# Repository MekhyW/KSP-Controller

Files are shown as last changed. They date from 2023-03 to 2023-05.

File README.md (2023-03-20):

# Projeto Embarcados

Desenvolvendo um controle remoto Bluetooth.

### Integrantes

- Ariel Leventhal
- Rafael Katri
- Felipe Catapano

### Ideia

A ideia do projeto é criar um controle bluetooth que simula um mission controller realista para o jogo Kerbal Space Program, assim aumentando a imersão do jogo e providenciando feedback visual diretamente no controle.
Com isso, os jogadores podem ter uma experiência mais envolvente e realista, sentindo-se como se estivessem realmente no comando de uma missão espacial. 
Para isso será usado uma placa SAME70-XPLD com vários periféricos e um módulo bluetooth HC-05.

### O Que é o Kerbal Space Program?

KSP
Kerbal Space Program é um jogo de simulação espacial desenvolvido pela Squad e lançado em 2011. Nele, o jogador assume o papel de administrador de uma agência espacial fictícia e deve construir e gerenciar naves espaciais, realizar missões de exploração e pesquisa em um sistema solar simulado.

O jogo possui um alto grau de realismo, com física e mecânica orbital precisas, o que significa que o jogador deve levar em conta fatores como a gravidade, a atmosfera, o peso e o empuxo ao projetar e lançar suas naves. Além disso, os kerbals, criaturas humanoides verdes que habitam o jogo, são os tripulantes dessas naves e também possuem suas próprias habilidades e limitações.

Kerbal Space Program é um jogo desafiador e educativo, que exige planejamento cuidadoso e pensamento crítico para alcançar objetivos no espaço. Ele também se tornou um fenômeno na comunidade de jogos e exploração espacial, com muitos jogadores construindo e compartilhando suas próprias criações e mods para o jogo.

### Nome
Valdisnei da Chroma 2:
16.6 milhões de cores

### Usuários 

Jogadores de Kerbal Space Program e admiradores do valdisnei.

### Software/Jogo 

Kerbal space  program (KSP), utilizando mod kRPC
O mod possibilita que o jogo seja controlado através da seguinte biblioteca: https://krpc.github.io/krpc/

### Jornada do usuários
Jornada 1:

&nbsp;&nbsp;&nbsp;&nbsp;&nbsp;&nbsp;O usuário entra no jogo Kerbal Space e ativa o mod de comunicação com o controle.  Em seguida, ele inicia a gameplay usando o slider de throttle (potenciometro linear) e aperta botão de estagio para acionar os motores da nave. Antes de entrar em órbita, o usuário vê pela resposta visual dos botões de Action Group que o combustível está acabando. 
        Ele usa a chave alavanca de Abort para iniciar o protocolo de emergência que ejeta a capsula do piloto e arma o paraquedas para ser aberto automaticamente quando a velocidade e altitude forem adequadas.

Jornada 2:

&nbsp;&nbsp;&nbsp;&nbsp;&nbsp;&nbsp;O usuário entra no jogo Kerbal Space e ativa o mod de comunicação com o controle. Em seguida, ele inicia a gameplay usando o slider de throttle (potenciometro linear) e aperta botão de estagio para acionar os motores da nave. Através das leds o jogador ve que o combustivel do primeiro estagio acabou entao ele aperta botao stage para fazer separacao de estagio. Em seguida o combustivel do segundo estagio acaba tambem (essa e uma missao sub-orbital). Entao o jogador aperta o botao estagio novamente para ejetar o motor, e ativa o action group de paraquedas.

### Comandos/ Feedbacks do jogo

#### Comandos
* Throttle 
* Abort
* Actions groups (paraquedas, trem de pouso, freio, etc); por volta de 7.
* Proximo estagio
* Controle de estabilidade automatico
* Controle de reacao

#### Feeback

* Estado dos Actions groups (paraquedas, trem de pouso, freio, etc); por volta de 7
* Estado da missao
* Estado Controle de estabilidade automatico
* Estado Controle de reacao
* Niveis de combustivel e Agente Oxidante

## In/OUT
#### IN
* Throttle: Potenciometro Linear
* Abort: Chave alanvaca
* Actions groups (paraquedas, trem de pouso, freio, etc); por volta de 7: Push button Retroiluminado.
* Proximo estagio: Push button retro iluminado
* Controle de estabilidade automatico: Chave alavanca para ativar e  Push button RGB para ciclar modos
* Controle de reacao: push button retroiluminado

#### Out

* Estado dos Actions groups (paraquedas, trem de pouso, freio, etc); por volta de 7: Led dos botoes
* Estado da missao: led do botao de estagio
* Estado Controle de estabilidade automatico: Cor da led do botao
* Estado Controle de reacao: Led do botao
* Niveis de combustivel e Agente Oxidante: Segmento de fita led RGB.
### Design

O design do controle foi inspirado nas seguintes criações da comunidade de KSP:
KSP
KSP
KSP

O nosso design segue esse layout:
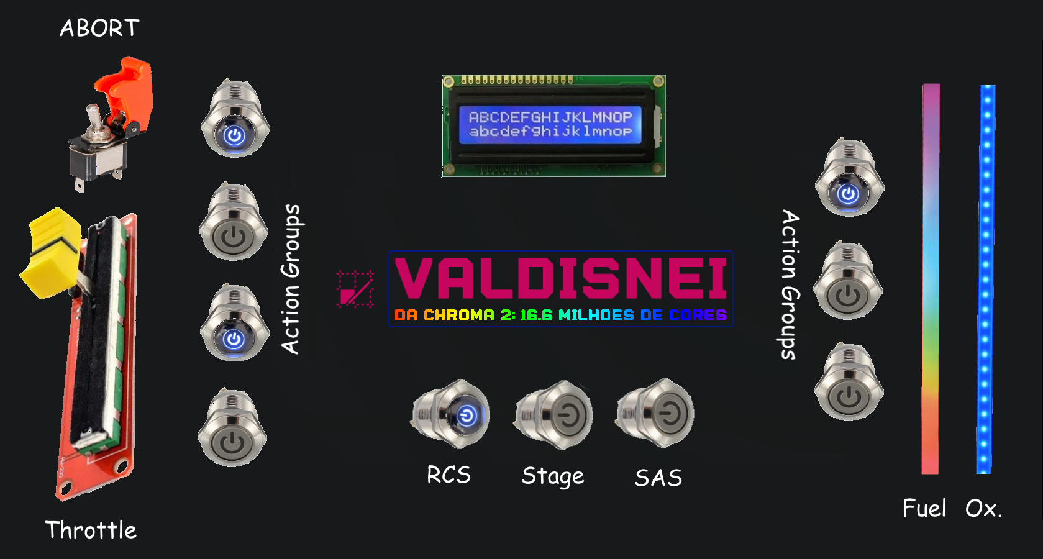
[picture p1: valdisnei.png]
KSP


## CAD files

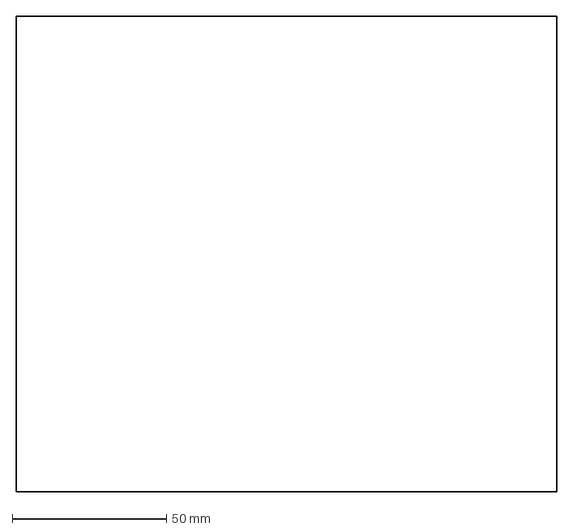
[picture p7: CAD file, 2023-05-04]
Case 3D/box_floor.dxf
175.2 x 154.0 mm

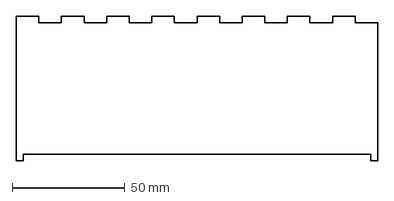
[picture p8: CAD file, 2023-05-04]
Case 3D/box_side.dxf
160.0 x 64.0 mm

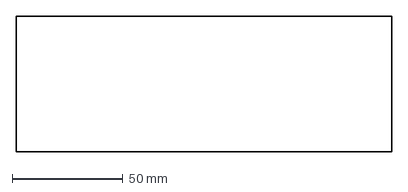
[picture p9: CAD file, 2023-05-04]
Case 3D/box_back.dxf
169.2 x 61.0 mm

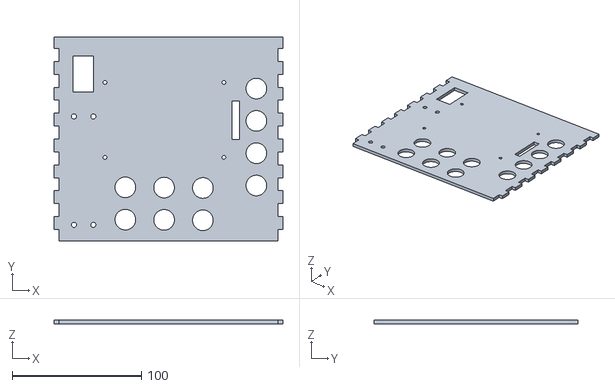
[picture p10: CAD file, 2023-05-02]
Case 3D/tampa.stl
177.2 x 158.0 x 3.00

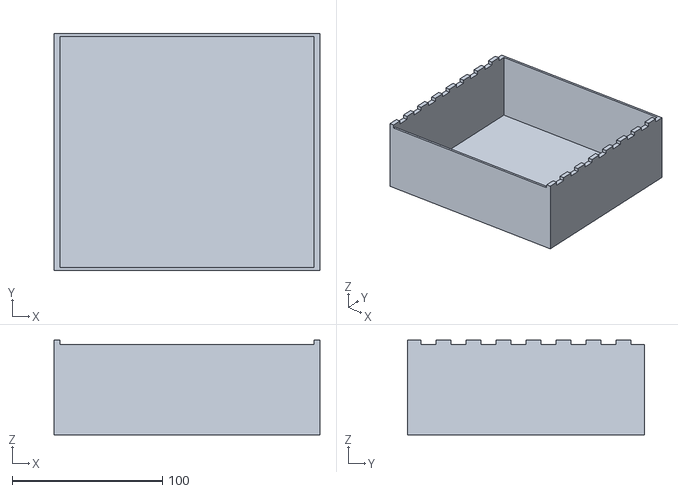
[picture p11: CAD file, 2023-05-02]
Case 3D/caixa.stl
177.2 x 158.0 x 63.0

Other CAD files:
Case 3D/controller.f3d

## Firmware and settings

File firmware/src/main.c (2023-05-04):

#include "abort.h"
#include "backlit-buttons.h"
#include "conf_board.h"
#include "throttle.h"
#include <asf.h>
#include <string.h>

/************************************************************************/
/* defines                                                              */
/************************************************************************/

// usart (bluetooth ou serial)
// Descomente para enviar dados
// pela serial debug

#define DEBUG_SERIAL

#ifdef DEBUG_SERIAL
#define USART_COM USART1
#define USART_COM_ID ID_USART1
#else
#define USART_COM USART0
#define USART_COM_ID ID_USART0
#endif

/************************************************************************/
/* RTOS                                                                 */
/************************************************************************/

#define TASK_BLUETOOTH_STACK_SIZE (4096 / sizeof(portSTACK_TYPE))
#define TASK_BLUETOOTH_STACK_PRIORITY (tskIDLE_PRIORITY)

/************************************************************************/
/* prototypes                                                           */
/************************************************************************/

extern void vApplicationStackOverflowHook(xTaskHandle *pxTask,
                                          signed char *pcTaskName);
extern void vApplicationIdleHook(void);
extern void vApplicationTickHook(void);
extern void vApplicationMallocFailedHook(void);
extern void xPortSysTickHandler(void);

/************************************************************************/
/* variaveis globais                                                    */
/************************************************************************/

volatile char estado[] = {0, 0};
volatile int throttle = 0;

/************************************************************************/
/* RTOS application HOOK                                                */
/************************************************************************/

extern void vApplicationStackOverflowHook(xTaskHandle *pxTask,
                                          signed char *pcTaskName) {
    printf("stack overflow %x %s\r\n", pxTask, (portCHAR *)pcTaskName);
    for (;;) {
    }
}
extern void vApplicationIdleHook(void) {
    pmc_sleep(SAM_PM_SMODE_SLEEP_WFI);
}
extern void vApplicationTickHook(void) {}
extern void vApplicationMallocFailedHook(void) {
    configASSERT((volatile void *)NULL);
}

/************************************************************************/
/* handlers / callbacks                                                 */
/************************************************************************/

static void AFEC_pot_callback(void) {
    double temp_throttle = afec_channel_get_value(AFEC_POT, AFEC_POT_CHANNEL);
    temp_throttle /= 4096;
    temp_throttle *= 127;
    throttle = (throttle * 0.5) + (temp_throttle * 0.5);
}

/************************************************************************/
/* funcoes                                                              */
/************************************************************************/

void io_init(void) {
    pmc_enable_periph_clk(BUT1_PIO_ID);
    pmc_enable_periph_clk(BUT2_PIO_ID);
    pmc_enable_periph_clk(BUT3_PIO_ID);
    pmc_enable_periph_clk(BUT4_PIO_ID);
    pmc_enable_periph_clk(BUT5_PIO_ID);
    pmc_enable_periph_clk(BUT6_PIO_ID);
    pmc_enable_periph_clk(BUT7_PIO_ID);
    pmc_enable_periph_clk(BUT8_PIO_ID);
    pmc_enable_periph_clk(BUT9_PIO_ID);
    pmc_enable_periph_clk(BUT10_PIO_ID);
    pmc_enable_periph_clk(ABORT_PIO_ID);
    pio_configure(BUT1_PIO, PIO_INPUT, BUT1_IDX_MASK, PIO_PULLUP | PIO_DEBOUNCE);
    pio_set_debounce_filter(BUT1_PIO, BUT1_IDX_MASK, 100);
    pio_configure(BUT2_PIO, PIO_INPUT, BUT2_IDX_MASK, PIO_PULLUP | PIO_DEBOUNCE);
    pio_set_debounce_filter(BUT2_PIO, BUT2_IDX_MASK, 100);
    pio_configure(BUT3_PIO, PIO_INPUT, BUT3_IDX_MASK, PIO_PULLUP | PIO_DEBOUNCE);
    pio_set_debounce_filter(BUT3_PIO, BUT3_IDX_MASK, 100);
    pio_configure(BUT4_PIO, PIO_INPUT, BUT4_IDX_MASK, PIO_PULLUP | PIO_DEBOUNCE);
    pio_set_debounce_filter(BUT4_PIO, BUT4_IDX_MASK, 100);
    pio_configure(BUT5_PIO, PIO_INPUT, BUT5_IDX_MASK, PIO_PULLUP | PIO_DEBOUNCE);
    pio_set_debounce_filter(BUT5_PIO, BUT5_IDX_MASK, 100);
    pio_configure(BUT6_PIO, PIO_INPUT, BUT6_IDX_MASK, PIO_PULLUP | PIO_DEBOUNCE);
    pio_set_debounce_filter(BUT6_PIO, BUT6_IDX_MASK, 100);
    pio_configure(BUT7_PIO, PIO_INPUT, BUT7_IDX_MASK, PIO_PULLUP | PIO_DEBOUNCE);
    pio_set_debounce_filter(BUT7_PIO, BUT7_IDX_MASK, 100);
    pio_configure(BUT8_PIO, PIO_INPUT, BUT8_IDX_MASK, PIO_PULLUP | PIO_DEBOUNCE);
    pio_set_debounce_filter(BUT8_PIO, BUT8_IDX_MASK, 100);
    pio_configure(BUT9_PIO, PIO_INPUT, BUT9_IDX_MASK, PIO_PULLUP | PIO_DEBOUNCE);
    pio_set_debounce_filter(BUT9_PIO, BUT9_IDX_MASK, 100);
    pio_configure(BUT10_PIO, PIO_INPUT, BUT10_IDX_MASK, PIO_PULLUP | PIO_DEBOUNCE);
    pio_set_debounce_filter(BUT10_PIO, BUT10_IDX_MASK, 100);
    pio_configure(ABORT_PIO, PIO_INPUT, ABORT_IDX_MASK, PIO_PULLUP | PIO_DEBOUNCE);
    pio_set_debounce_filter(ABORT_PIO, ABORT_IDX_MASK, 100);

    pmc_enable_periph_clk(LED_PIO_ID);
    pio_set_output(LED_PIO, LED_IDX_MASK, 1, 0, 0);
	 pmc_enable_periph_clk(LED1_PIO_ID);
	 pio_set_output(LED1_PIO, LED1_IDX_MASK, 1, 0, 0);
    pmc_enable_periph_clk(LED2_PIO_ID);
    pio_set_output(LED2_PIO, LED2_IDX_MASK, 1, 0, 0);
    pmc_enable_periph_clk(LED3_PIO_ID);
    pio_set_output(LED3_PIO, LED3_IDX_MASK, 1, 0, 0);
    pmc_enable_periph_clk(LED4_PIO_ID);
    pio_set_output(LED4_PIO, LED4_IDX_MASK, 1, 0, 0);
    pmc_enable_periph_clk(LED5_PIO_ID);
    pio_set_output(LED5_PIO, LED5_IDX_MASK, 1, 0, 0);
    pmc_enable_periph_clk(LED6_PIO_ID);
    pio_set_output(LED6_PIO, LED6_IDX_MASK, 1, 0, 0);
    pmc_enable_periph_clk(LED7_PIO_ID);
    pio_set_output(LED7_PIO, LED7_IDX_MASK, 1, 0, 0);
    pmc_enable_periph_clk(LED8_PIO_ID);
    pio_set_output(LED8_PIO, LED8_IDX_MASK, 1, 0, 0);
    pmc_enable_periph_clk(LED9_PIO_ID);
    pio_set_output(LED9_PIO, LED9_IDX_MASK, 1, 0, 0);
    pmc_enable_periph_clk(LED10_PIO_ID);
    pio_set_output(LED10_PIO, LED10_IDX_MASK, 1, 0, 0);
    pmc_enable_periph_clk(LED11_PIO_ID);
    pio_set_output(LED11_PIO, LED11_IDX_MASK, 1, 0, 0);
    pmc_enable_periph_clk(LED12_PIO_ID);
    pio_set_output(LED12_PIO, LED12_IDX_MASK, 1, 0, 0);
    pmc_enable_periph_clk(LED_ABORT_PIO_ID);
    pio_set_output(LED_ABORT_PIO, LED_ABORT_IDX_MASK, 0, 0, 0);

  
}

void read_but(void) {
    estado[0] = 0 | (!pio_get(BUT1_PIO, PIO_INPUT, BUT1_IDX_MASK) << 0);
    estado[0] = estado[0] | (!pio_get(BUT2_PIO, PIO_INPUT, BUT2_IDX_MASK) << 1);
    estado[0] = estado[0] | (!pio_get(BUT3_PIO, PIO_INPUT, BUT3_IDX_MASK) << 2);
    estado[0] = estado[0] | (!pio_get(BUT4_PIO, PIO_INPUT, BUT4_IDX_MASK) << 3);
    estado[0] = estado[0] | (!pio_get(BUT5_PIO, PIO_INPUT, BUT5_IDX_MASK) << 4);
    estado[0] = estado[0] | (!pio_get(BUT6_PIO, PIO_INPUT, BUT6_IDX_MASK) << 5);
    estado[0] = estado[0] | (!pio_get(BUT7_PIO, PIO_INPUT, BUT7_IDX_MASK) << 6);
    estado[1] = 0 | (!pio_get(BUT8_PIO, PIO_INPUT, BUT8_IDX_MASK) << 0);
    estado[1] = estado[1] | (!pio_get(BUT9_PIO, PIO_INPUT, BUT9_IDX_MASK) << 1);
    estado[1] = estado[1] | (!pio_get(BUT10_PIO, PIO_INPUT, BUT10_IDX_MASK) << 2);
    estado[1] = estado[1] | (!pio_get(ABORT_PIO, PIO_INPUT, ABORT_IDX_MASK) << 3);
 
}
void led_set(Pio *pio, uint32_t mask ,int estado) {
    if (estado){
        pio_clear(pio,mask);
    } else {
        pio_set(pio,mask);
    }
}
void write_leds1(char data){
    led_set(LED1_PIO,LED1_IDX_MASK,data & 0x01);
    led_set(LED2_PIO,LED2_IDX_MASK,data & 0x02);
    led_set(LED3_PIO,LED3_IDX_MASK,data & 0x04);
    led_set(LED4_PIO,LED4_IDX_MASK,data & 0x08);
    led_set(LED5_PIO,LED5_IDX_MASK,data & 0x10);
    led_set(LED6_PIO,LED6_IDX_MASK,data & 0x20);
    led_set(LED_ABORT_PIO,LED_ABORT_IDX_MASK,data & 0x40);
	
}
void write_leds2(char data){
    led_set(LED8_PIO,LED8_IDX_MASK,data & 0x01);
    led_set(LED9_PIO,LED9_IDX_MASK,data & 0x02);
    led_set(LED10_PIO,LED10_IDX_MASK,data & 0x04);
    led_set(LED11_PIO,LED11_IDX_MASK,data & 0x08);
    led_set(LED12_PIO,LED12_IDX_MASK,data & 0x10);
}
static void config_AFEC_pot(Afec *afec, uint32_t afec_id, uint32_t afec_channel, afec_callback_t callback) {
    afec_enable(afec);
    struct afec_config afec_cfg;
    afec_get_config_defaults(&afec_cfg);
    afec_init(afec, &afec_cfg);
    afec_set_trigger(afec, AFEC_TRIG_SW);
    struct afec_ch_config afec_ch_cfg;
    afec_ch_get_config_defaults(&afec_ch_cfg);
    afec_ch_cfg.gain = AFEC_GAINVALUE_0;
    afec_ch_set_config(afec, afec_channel, &afec_ch_cfg);
    afec_channel_set_analog_offset(afec, afec_channel, 0x200);
    struct afec_temp_sensor_config afec_temp_sensor_cfg;
    afec_temp_sensor_get_config_defaults(&afec_temp_sensor_cfg);
    afec_temp_sensor_set_config(afec, &afec_temp_sensor_cfg);
    afec_set_callback(afec, afec_channel, callback, 1);
    NVIC_SetPriority(afec_id, 4);
    NVIC_EnableIRQ(afec_id);
}

static void configure_console(void) {
    const usart_serial_options_t uart_serial_options = {
        .baudrate = CONF_UART_BAUDRATE,
#if (defined CONF_UART_CHAR_LENGTH)
        .charlength = CONF_UART_CHAR_LENGTH,
#endif
        .paritytype = CONF_UART_PARITY,
#if (defined CONF_UART_STOP_BITS)
        .stopbits = CONF_UART_STOP_BITS,
#endif
    };
    stdio_serial_init(CONF_UART, &uart_serial_options);
#if defined(__GNUC__)
    setbuf(stdout, NULL);
#else
#endif
}

uint32_t usart_puts(uint8_t *pstring) {
    uint32_t i;
    while (*(pstring + i))
        if (uart_is_tx_empty(USART_COM))
            usart_serial_putchar(USART_COM, *(pstring + i++));
}

void usart_put_string(Usart *usart, char str[]) {
    usart_serial_write_packet(usart, str, strlen(str));
}

int usart_get_string(Usart *usart, char buffer[], int bufferlen, uint timeout_ms) {
    uint timecounter = timeout_ms;
    uint32_t rx;
    uint32_t counter = 0;
    while ((timecounter > 0) && (counter < bufferlen - 1)) {
        if (usart_read(usart, &rx) == 0) {
            buffer[counter++] = rx;
        } else {
            timecounter--;
            vTaskDelay(1);
        }
    }
    buffer[counter] = 0x00;
    return counter;
}

void usart_send_command(Usart *usart, char buffer_rx[], int bufferlen,
                        char buffer_tx[], int timeout) {
    usart_put_string(usart, buffer_tx);
    usart_get_string(usart, buffer_rx, bufferlen, timeout);
}

void config_usart0(void) {
    sysclk_enable_peripheral_clock(ID_USART0);
    usart_serial_options_t config;
    config.baudrate = 9600;
    config.charlength = US_MR_CHRL_8_BIT;
    config.paritytype = US_MR_PAR_NO;
    config.stopbits = false;
    usart_serial_init(USART0, &config);
    usart_enable_tx(USART0);
    usart_enable_rx(USART0);
    // RX - PB0  TX - PB1
    pio_configure(PIOB, PIO_PERIPH_C, (1 << 0), PIO_DEFAULT);
    pio_configure(PIOB, PIO_PERIPH_C, (1 << 1), PIO_DEFAULT);
}

int hc05_init(void) {
    char buffer_rx[128];
    usart_send_command(USART_COM, buffer_rx, 1000, "AT", 100);
    vTaskDelay(500 / portTICK_PERIOD_MS);
    usart_send_command(USART_COM, buffer_rx, 1000, "AT", 100);
    vTaskDelay(500 / portTICK_PERIOD_MS);
    usart_send_command(USART_COM, buffer_rx, 1000, "AT+NAMEagoravai", 100);
    vTaskDelay(500 / portTICK_PERIOD_MS);
    usart_send_command(USART_COM, buffer_rx, 1000, "AT", 100);
    vTaskDelay(500 / portTICK_PERIOD_MS);
    usart_send_command(USART_COM, buffer_rx, 1000, "AT+PIN0000", 100);
}

/************************************************************************/
/* TASKS                                                                */
/************************************************************************/

void task_bluetooth(void) {
    char button1 = '0';
    char eof = -1;
    while (1) {
        read_but();
        // envia status botões e abort
        while (!usart_is_tx_ready(USART_COM)) {
            vTaskDelay(10 / portTICK_PERIOD_MS);
        }
        usart_write(USART_COM, estado[0]);
        while (!usart_is_tx_ready(USART_COM)) {
            vTaskDelay(10 / portTICK_PERIOD_MS);
        }
        usart_write(USART_COM, estado[1]);

        // envia status throttle
        while (!usart_is_tx_ready(USART_COM)) {
            vTaskDelay(10 / portTICK_PERIOD_MS);
        }
        usart_write(USART_COM, throttle);
        afec_channel_enable(AFEC_POT, AFEC_POT_CHANNEL);
        afec_start_software_conversion(AFEC_POT);

        // envia fim de pacote
        while (!usart_is_tx_ready(USART_COM)) {
            vTaskDelay(10 / portTICK_PERIOD_MS);
        }
        usart_write(USART_COM, eof);

        // dorme por 10 ms
        vTaskDelay(1 / portTICK_PERIOD_MS);
    }
}

void task_read(void) {
    char buffer_rx;
    char event_buffer;
    int waiting_data = 0;

    while (1) {

        while (!usart_is_rx_ready(USART_COM)) {
            vTaskDelay(10 / portTICK_PERIOD_MS);
        }
        int res = usart_read(USART_COM, &buffer_rx);
		if (res) continue;
        if (waiting_data) {
          
				
            if (event_buffer == 128) {
                write_leds1(buffer_rx);
            } else if (event_buffer == 129){
                write_leds2(buffer_rx);
            }

            waiting_data = 0;
        }
        if (buffer_rx >= 128) {
            event_buffer = buffer_rx;
            waiting_data = 1;
        }
    }
}
/************************************************************************/
/* main                                                                 */
/************************************************************************/

int main(void) {
    sysclk_init();
    board_init();
    configure_console();
    config_usart0();
    // hc05_init();
    io_init();
    config_AFEC_pot(AFEC_POT, AFEC_POT_ID, AFEC_POT_CHANNEL, AFEC_pot_callback);
    xTaskCreate(task_bluetooth, "BLT", TASK_BLUETOOTH_STACK_SIZE, NULL,	TASK_BLUETOOTH_STACK_PRIORITY, NULL);
    xTaskCreate(task_read, "READ", TASK_BLUETOOTH_STACK_SIZE, NULL, TASK_BLUETOOTH_STACK_PRIORITY, NULL);
    vTaskStartScheduler();
    while (1) {
    }
    return 0;
}

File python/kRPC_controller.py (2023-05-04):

import krpc
import serial
# import argparse
import time
from threading import Thread
# import logging
byteDelay = 0.02
abort = False
conn = krpc.connect(name='Launch into orbit')
vessel = conn.space_center.active_vessel
def calc_color():
    sit = vessel.situation
    print(sit.name)
    if abort:
        return (1,0,0)
    elif sit.name=="pre_launch":
        return (0,1,1)
    elif sit.name=="flying":
        return (0,0,1)
    elif sit.name=="sub_orbital":
        return (0,1,1)
    elif sit.name=="orbiting" or sit.name=="escaping":
        return (0,1,0)
    elif sit.name=="landed" or sit.name=="splashed" or sit.name=="docked":
        return (1,0,1)
    
    else:
        return (1,1,1)
    
def write_data(ser):
    while True:
        ctr = vessel.control
        color = calc_color()
        ser.write(bytes([0x80]))
        time.sleep(byteDelay)
        ser.write(bytes([ctr.gear+2*ctr.brakes+4*ctr.parachutes+8*ctr.lights+16*ctr.get_action_group(1)+32*ctr.get_action_group(2)+64*(not abort)]))
        time.sleep(byteDelay)
        ser.write(bytes([0x81]))
        time.sleep(byteDelay)
        ser.write(bytes([vessel.control.sas+2*vessel.control.rcs+4*color[0]+8*color[1]+16*color[2]]))
        time.sleep(byteDelay)


with serial.Serial('COM3', 115200,timeout=1,) as ser:
    last_state = [-1,-1,-1,-1]
    write_data_thread = Thread(target=write_data,args=[ser],daemon=True)
    write_data_thread.start()
    while True:
        data = ser.read_until(bytes([255]))
        while len(data) <4:
            data += ser.read_until(bytes([255]))
        vessel.control.throttle = min(1,data[2]/124)
        if not vessel.control.abort:
            abort = False
        if not (last_state[1]&2) and data[1]&2:
            vessel.control.rcs = not vessel.control.rcs
        if not (last_state[1]&1) and data[1]&1:
            vessel.control.sas = not vessel.control.sas
        if not (last_state[1]&4) and data[1]&4:
            vessel.control.activate_next_stage()
        if not (last_state[1]&8) and data[1]&8:
            abort = True
            vessel.control.abort = True
        if not (last_state[0]&1) and data[0]&1:
            vessel.control.gear = not vessel.control.gear
        if not (last_state[0]&2) and data[0]&2:
            vessel.control.brakes = not vessel.control.brakes
        if not (last_state[0]&4) and data[0]&4:
            vessel.control.parachutes = True
        if not (last_state[0]&8) and data[0]&8:
            vessel.control.lights = not vessel.control.lights
        if not (last_state[0]&16) and data[0]&16:
            vessel.control.toggle_action_group(1)
        if not (last_state[0]&32) and data[0]&32:
            vessel.control.toggle_action_group(2)
        
        
        last_state = data

        

                
  

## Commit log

2023-04-28 Throttle (só printa por enquanto)
2023-05-02 3D models
    [caixa.stl, controller.f3d, tampa.stl]
2023-05-02 Updated 3d model
    [caixa.stl, controller.f3d, tampa.stl]
2023-05-03 box laserfiles
    [box_back.dxf, box_floor.dxf, box_side.dxf]
